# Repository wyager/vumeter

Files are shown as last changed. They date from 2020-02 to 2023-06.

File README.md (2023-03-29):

# Nixie Tube Audio Meter

Picture of VU meter

A full writeup is available [here](http://yager.io/vumeter/vu.html).

## Directory Structure
* schematics
    * tube-board - the board that powers and controls the nixie tubes
    * tube-offset-1,2 - PCBs that hold the tubes in place
    * audio-board - a teensy-based board that takes in S/PDIF audio over TOSLINK, does DSP, and outputs control data to the tube boards
    * custom - custom kicad parts for this project
    * case - freecad designs and macros for the case, plus some resultant SVGs I used to laser-cut the acrylic
    * bom - a list of some non-commodity part numbers
* code
    * audio-board - the code for the board that reads in S/PDIF audio over TOSLINK, does DSP, and controls the tube boards
    * linux-control - some code for controlling the tube boards from Linux/mac. Mostly used for testing.
    * test - used for testing the DSP code on desktop
    * tube-board - code for the board that powers/controls the bargraph tubes
    * vumeter-lib - hardware-independent code

## Building the code

Go into `code/audio_board` and `code/tube_board` and run `cargo build --release`. (Without `--release`, the binaries may be too large.)

## Uploading the code

First, build the code.

### Tube board

Go into `code/tube_board`.

Plug your AVR-ICE or similar JTAG programmer into the tube board via the programming header and run `./program.sh`.

### Audio Board

Go into `code/audio_board`.

Plug in your teensy over USB, put it in programming mode, and run `./program.sh`

## Building the PCBs

Get KiCad and open the schematics. How to export the schematics depends on your choice of PCB manufacturer. They should have instructions available online.

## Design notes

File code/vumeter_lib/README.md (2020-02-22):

This library contains the hardware-independent bits of the vumeter project, including:

* Packet protocol definitions, parsers/formatters, etc. etc.
* DSP code
* The core logic of the audio and tube boards, with the hardware details abstracted away

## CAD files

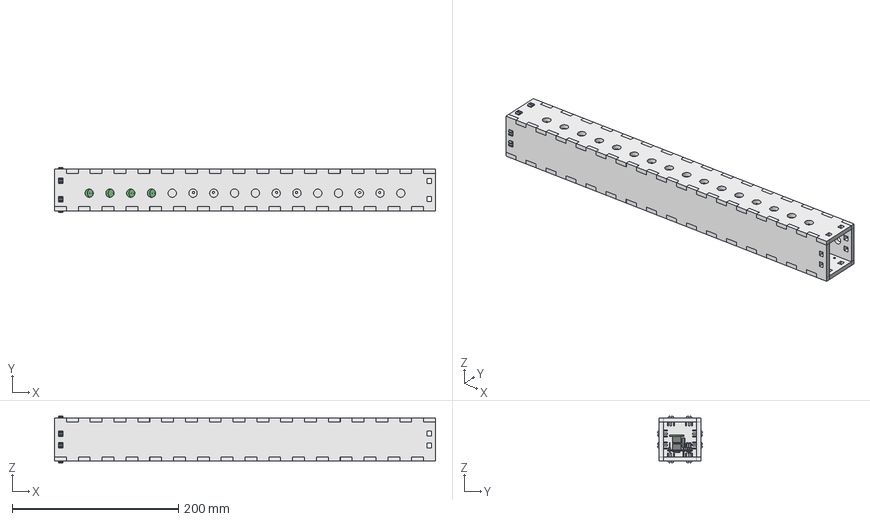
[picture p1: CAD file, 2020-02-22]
schematics/case/bottom.FCStd
458.4 x 54.2 x 56.2 mm
offset-b-001
base_extr
back_extr
front_extr
top_extr
side_extr

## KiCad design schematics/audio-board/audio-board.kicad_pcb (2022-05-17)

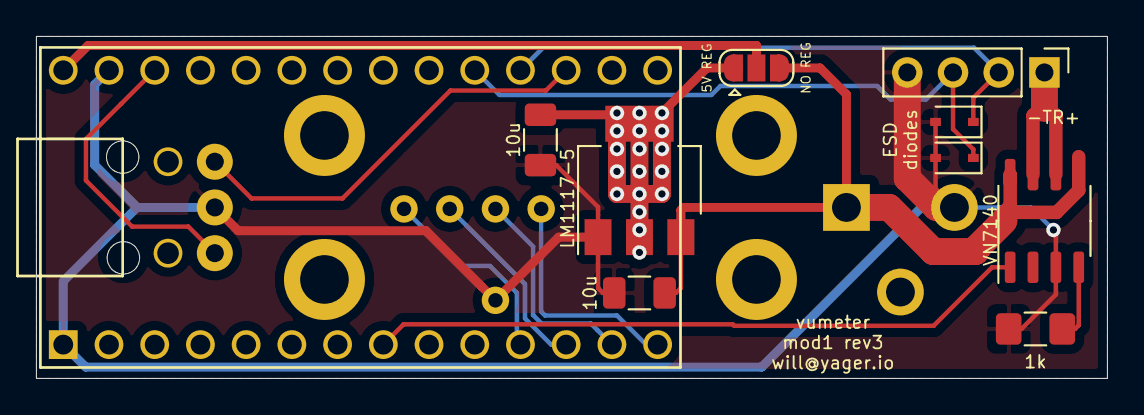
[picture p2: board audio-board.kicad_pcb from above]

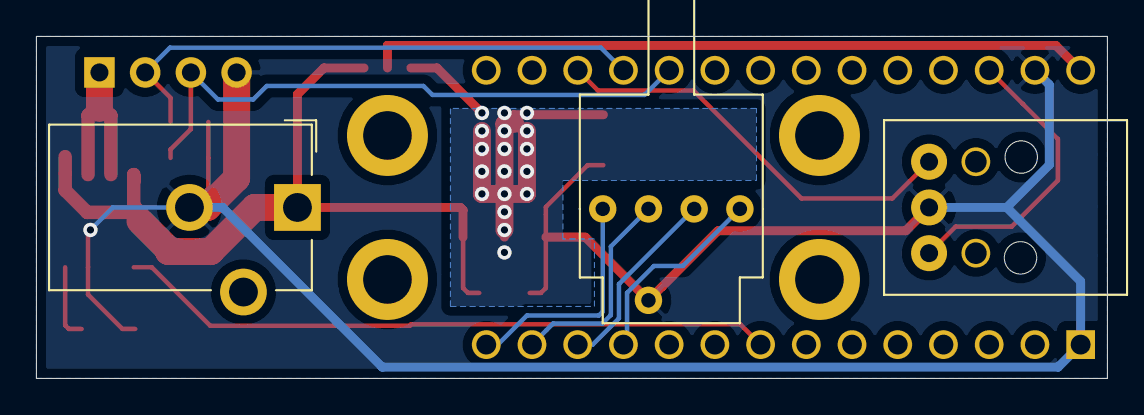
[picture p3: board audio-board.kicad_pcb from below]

Board: 2 copper layers, 59.5 x 19.0 mm, 17 parts (3 on the bottom side), 15 nets.

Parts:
C_pwr1, C_pwr2: 10u; C_1206_3216Metric
D1, D2: BZX384-xxx; D_SOD-323
H1, H2, H3, H4: MountingHole_Pad; MountingHole_2.7mm_M2.5_ISO14580_Pad
J3: Conn_01x04; PinHeader_1x04_P2.54mm_Vertical
J4: Conn_Coaxial_Power; BarrelJack_CUI_PJ-102AH_Horizontal
R1: 1k; R_1206_3216Metric_Pad1.42x1.75mm_HandSolder
SW1: 5V_BYPASS; SolderJumper-3_P1.3mm_Open_RoundedPad1.0x1.5mm
U1: Teensy4.0; Teensy40
U2: spdif_recv; Cliff_ORJ-8
U3: LM1117-5; SOT-223-3_TabPin2
U5: S-2151
U6: VN7140; SO-8_3.9x4.9mm_P1.27mm

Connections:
3V3: U1.31, U2.3
5V: C_pwr2.1, SW1.1, U3.2
GND: C_pwr1.1, C_pwr2.2, D1.2, D2.2, J3.4, J4.2, R1.1, U1.1, U1.32, U2.2, U3.1, U5.5, U6.3
unnamed: R1.2, U6.4
unnamed: U1.11, U5.4
unnamed: U1.12, U5.3
unnamed: U1.13, U5.2
unnamed: U1.14, U5.1
unnamed: U1.22, U2.1
TEENSY_5V_SUPPLY: SW1.2, U1.33
V_mid: C_pwr1.2, J4.1, SW1.3, U3.3, U6.5, U6.8
V_mid_out: J3.1, U6.6, U6.7
output_power_en: U1.8, U6.1
rx2: D2.1, J3.2, U1.23
tx2: D1.1, J3.3, U1.24

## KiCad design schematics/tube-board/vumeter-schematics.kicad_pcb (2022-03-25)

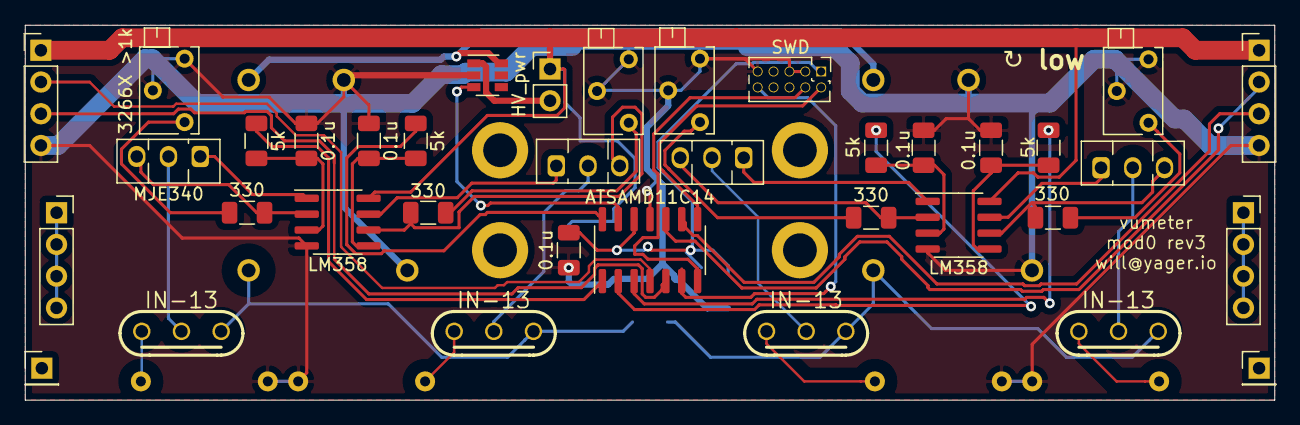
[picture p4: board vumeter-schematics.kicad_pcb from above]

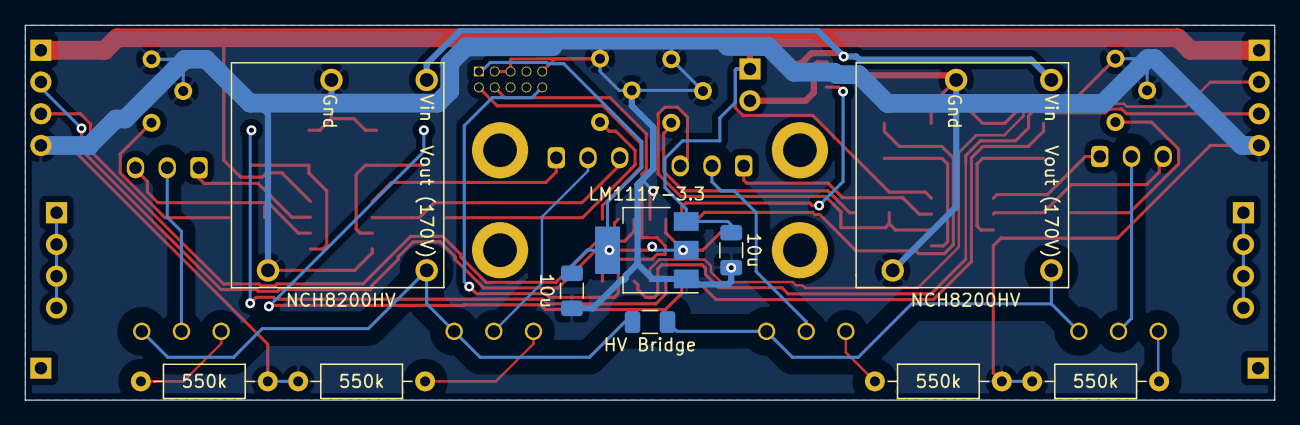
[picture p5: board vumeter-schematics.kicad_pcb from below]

Board: 2 copper layers, 100.0 x 30.0 mm, 51 parts (10 on the bottom side), 45 nets.

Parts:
C_decouple1: 0.1u; C_1206_3216Metric
C_pwm1, C_pwm2, C_pwm3, C_pwm4: 0.1u; C_1206_3216Metric
C_pwr1, C_pwr2: 10u; C_1206_3216Metric
H1, H2, H3, H4: MountingHole_Pad; MountingHole_2.7mm_M2.5_ISO14580_Pad
J1: SWD; PinHeader_2x05_P1.27mm_Vertical-smallholes
J2, J3: Conn_01x04; PinHeader_1x04_P2.54mm_Vertical
J4: Standoff_1; PinSocket_1x04_P2.54mm_Vertical
J5: Standoff_2; PinSocket_1x04_P2.54mm_Vertical
J6, J7: Conn_01x01_Male; PinHeader_1x01_P2.54mm_Vertical
JP1: HV Bridge; R_1206_3216Metric
JP2: HV_pwr; PinHeader_1x02_P2.54mm_Vertical
N1, N2, N3, N4: IN-13; fixed-IN-13-footprint-wide-sockets
Q1, Q2, Q3, Q4: MJE340; TO-126-3_Vertical-HV
R_Cathode1, R_Cathode2, R_Cathode3, R_Cathode4: 550k; R_Axial_DIN0207_L6.3mm_D2.5mm_P10.16mm_Horizontal
R_Sense1, R_Sense2, R_Sense3, R_Sense4: 330; R_1206_3216Metric
R_adj1, R_adj2, R_adj3, R_adj4: 3266X >1k; Potentiometer_Bourns_3266X_Horizontal
R_pwm1, R_pwm2, R_pwm3, R_pwm4: 5k; R_1206_3216Metric
U1, U4: LM358; SOIC-8_3.9x4.9mm_P1.27mm
U2: ATSAMD11C14; SOIC-14_3.9x8.7mm_P1.27mm
U3: LM1117-3.3; SOT-223-3_TabPin2
U5, U6: NCH8200HV
U7: TPS2281DBVR; SOT-23-6

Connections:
3V3: C_decouple1.1, C_pwr2.1, J1.1, U2.12, U3.2
GND: C_decouple1.2, C_pwm1.2, C_pwm2.2, C_pwm3.2, C_pwm4.2, C_pwr1.1, C_pwr2.2, J1.3, J1.5, J1.9, J2.4, J3.4, R_Cathode1.2, R_Cathode2.2, R_Cathode3.2, R_Cathode4.2, R_adj1.2, R_adj1.3, R_adj2.2, R_adj2.3, R_adj3.2, R_adj3.3, R_adj4.2, R_adj4.3, U1.4, U2.11, U3.1, U4.4, U5.2, U5.3, U6.2, U6.3, U7.2
HV1: JP1.2, N1.A, N2.A, U5.4
HV2: JP1.1, N3.A, N4.A, U6.4
M1: N1.K2, Q1.2
M2: N2.K2, Q2.2
M3: N3.K2, Q3.2
M4: N4.K2, Q4.2
M5: N1.K, R_Cathode1.1
M6: N2.K, R_Cathode2.1
M7: N3.K, R_Cathode3.1
M8: N4.K, R_Cathode4.1
unnamed: C_pwm1.1, R_pwm1.2, U1.3
unnamed: C_pwm2.1, R_pwm2.2, U1.5
unnamed: C_pwm3.1, R_pwm3.2, U4.3
unnamed: C_pwm4.1, R_pwm4.2, U4.5
unnamed: J4.1, J4.2, J4.3, J4.4
unnamed: J5.1, J5.2, J5.3, J5.4
unnamed: JP2.2, U7.1
unnamed: Q1.1, U1.1
unnamed: Q1.3, R_Sense1.1, U1.2
unnamed: Q2.1, U1.7
unnamed: Q2.3, R_Sense2.1, U1.6
unnamed: Q3.1, U4.1
unnamed: Q3.3, R_Sense3.1, U4.2
unnamed: Q4.1, U4.7
unnamed: Q4.3, R_Sense4.1, U4.6
unnamed: R_Sense1.2, R_adj1.1
unnamed: R_Sense2.2, R_adj2.1
unnamed: R_Sense3.2, R_adj3.1
unnamed: R_Sense4.2, R_adj4.1
unnamed: U5.1, U6.1, U7.6
PWM1: R_pwm1.1, U2.1
PWM2: R_pwm2.1, U2.14
PWM3: R_pwm3.1, U2.2
PWM4: R_pwm4.1, U2.3
V_mid: C_pwr1.2, J2.1, J3.1, JP2.1, U1.8, U3.3, U4.8
hv_en: U2.13, U7.3
rst: J1.10, U2.6
rx1: J2.2, U2.10
rx2: J3.3, U2.5
swclk: J1.4, U2.7
swdio: J1.2, U2.8
tx1: J2.3, U2.9
tx2: J3.2, U2.4

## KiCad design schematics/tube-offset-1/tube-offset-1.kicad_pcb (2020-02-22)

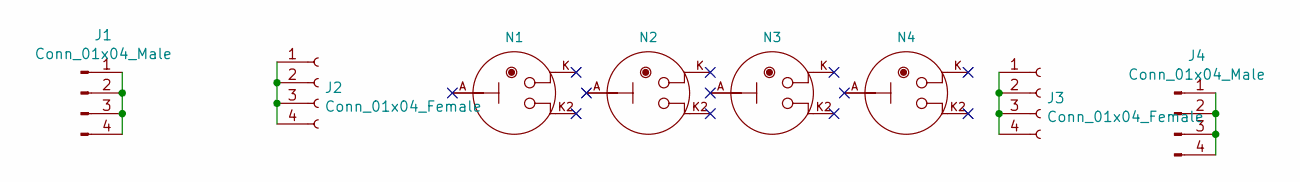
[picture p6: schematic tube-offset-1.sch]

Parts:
J1, J4: Conn_01x04_Male; PinSocket_1x04_P2.54mm_Vertical
J2, J3: Conn_01x04_Female; PinSocket_1x04_P2.54mm_Vertical
N1, N2, N3, N4: IN-13; fixed-IN-13-footprint

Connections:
unnamed: J1.1, J1.2, J1.3, J1.4
unnamed: J2.1, J2.2, J2.3, J2.4
unnamed: J3.1, J3.2, J3.3, J3.4
unnamed: J4.1, J4.2, J4.3, J4.4

Board: 2 copper layers, 8 parts (0 on the bottom side), 4 nets, no tracks yet.

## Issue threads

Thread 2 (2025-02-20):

Calibrate IN-13 !! PLZ !!!

0Bender, 2025-02-20:
I assembled a similar device from @holingher and it worked from the first launch :) https://github.com/holingher/vumeter_IN13
I have only one question. How to adjust the lamp level? How to set the maximum on the dumps? Maybe there is some kind of calibration? Thank you.

The author does not answer, but the devices are very similar.
I will be glad to any advice.

wyager, 2025-02-20:
Assuming the designs are similar, the blue trimpots are used to adjust the maximum tube level. On my design, there's a mode that puts all tubes to 100% so you can see where the max level sits as you adjust. Hope that helps!

0Bender, 2025-02-21:
Yes. I know about resistors :)
However, I tried to supply signals of different levels, but I still didn't understand which one is correct. 0dB or not. The maximum level mode only works when turned on.
However, because the code is different, I think I'll have to look for this mode from the developer.
Thanks!

Closed 2025-02-20.

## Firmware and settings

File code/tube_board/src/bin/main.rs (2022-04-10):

#![no_std]
#![no_main]

extern crate cortex_m_rt;
extern crate panic_halt;
extern crate vumeter_lib as vu;
extern crate atsamd11c;

#[macro_use(block)]
extern crate nb;



use atsamd_hal::clock::GenericClockController;
use samd11_bare::pac::{Peripherals,CorePeripherals};
use atsamd_hal::prelude::*;
use samd11_bare::pac::gclk::clkctrl::GEN_A;
use samd11_bare::pac::gclk::genctrl::SRC_A;
use atsamd_hal::sercom::{Sercom0, Sercom1};//{PadPin, Sercom0Pad0, Sercom0Pad1, Sercom1Pad2, Sercom1Pad3, UART0, UART1};
use embedded_hal::serial::{Read,Write};
use atsamd_hal::timer::TimerCounter;
// TODO: Figure out if one of the 2022 crates has wfi
//use cortex_m::asm::wfi;
use atsamd_hal::pwm::{Channel,Pwm0};
use atsamd_hal::time::{Hertz,KiloHertz};
use atsamd_hal::delay::Delay;
use atsamd_hal::gpio::{AlternateE, AlternateF, AlternateC};
use atsamd_hal::gpio::pin::{PA02, PA04, PA05, PA08, PA09, PA14, PA15, PA24, PA25};
use atsamd_hal::gpio::Pin;
use atsamd_hal::sercom::uart as uart;
use atsamd_hal::sercom::uart::BaudMode;
use atsamd_hal::sercom::uart::Oversampling;
use atsamd_hal::gpio::PushPullOutput;

use vu::tube_hw as hw;

use vu::shared::{RingBuf};
use hw::PWMPin::{A,B,C,D};

use samd11_bare::entry;

struct PowerPin(Pin<PA02, PushPullOutput>);

impl hw::DigitalOutput for PowerPin {
    fn set(&mut self, on : bool) {
        if on {self.0.set_high().unwrap()} else {self.0.set_low().unwrap()}
    }
}

struct PWMPins {
    pwm:Pwm0, _p1:Pin<PA04,AlternateF>, _p2:Pin<PA05,AlternateF>, _p3:Pin<PA08,AlternateE>, _p4:Pin<PA09,AlternateE>
}

impl hw::PWMx4 for PWMPins {
    fn get_max_duty(&self) -> u32 { self.pwm.get_max_duty() }
    fn set_duty(&mut self, pin : hw::PWMPin, duty : u32) {
        match pin {
            A => {self.pwm.set_duty(Channel::_1,duty)},
            B => {self.pwm.set_duty(Channel::_0,duty)},
            C => {self.pwm.set_duty(Channel::_2,duty)},
            D => {self.pwm.set_duty(Channel::_3,duty)}
        }
    }
}

#[entry]
fn main() -> ! {
    let mut peripherals = Peripherals::take().unwrap();
    let core = CorePeripherals::take().unwrap();

    // Initialize clocks
    let mut clocks = GenericClockController::with_internal_32kosc(
        peripherals.GCLK,
        &mut peripherals.PM,
        &mut peripherals.SYSCTRL,
        &mut peripherals.NVMCTRL,
    );
    clocks.configure_gclk_divider_and_source(GEN_A::GCLK2, 1, SRC_A::DFLL48M, false);
    let mut delay = Delay::new(core.SYST, &mut clocks);

    // Initialize 20Hz timer
    let gclk0 = clocks.gclk0();
    let timer_clock = clocks.tc1_tc2(&gclk0).unwrap();
    let mut timer = TimerCounter::tc1_(&timer_clock, peripherals.TC1, &mut peripherals.PM);
    timer.start(Hertz(20));

    // Initialize TCC0 PWM subsystem
    let tcc0clk = clocks.tcc0(&gclk0).unwrap();
    let pwm = Pwm0::new(&tcc0clk, KiloHertz(10), peripherals.TCC0, &mut peripherals.PM);

    let pins = samd11_bare::Pins::new(peripherals.PORT);
    // Enable PWM pins
    let p1 : Pin<PA04, AlternateF> = pins.d14.into_mode(); // parts.pa4.into_function_f(&mut parts.port);
    let p2 : Pin<PA05, AlternateF> = pins.d1.into_mode(); //parts.pa5.into_function_f(&mut parts.port);
    let p3 : Pin<PA08, AlternateE> = pins.d2.into_mode(); //parts.pa8.into_function_e(&mut parts.port);
    let p4 : Pin<PA09, AlternateE> = pins.d3.into_mode(); //parts.pa9.into_function_e(&mut parts.port);

    let pwm = PWMPins{pwm,_p1:p1,_p2:p2,_p3:p3,_p4:p4};

    // Initialize both left and right UARTs
    let gclk2 = clocks.get_gclk(GEN_A::GCLK2).expect("Could not get clock 2");
    let mut u1 = { 
        //let tx1: Sercom1Pad2<_> = parts.pa24.into_pull_down_input(&mut parts.port).into_pad(&mut parts.port);
        let tx1 : Pin<PA24, AlternateC> = pins.d9.into();
        //let rx1: Sercom1Pad3<_> = parts.pa25.into_pull_down_input(&mut parts.port).into_pad(&mut parts.port);
        let rx1 : Pin<PA25, AlternateC> = pins.d10.into();
        let uart_clk = clocks.sercom1_core(&gclk2).expect("Could not configure sercom1 clock");
        let pads = uart::Pads::<Sercom1>::default().rx(rx1).tx(tx1);
        //UART1::new(&uart_clk,Hertz(460800),peripherals.SERCOM1,&mut peripherals.PM,(rx1, tx1))
        let config = uart::Config::new(&peripherals.PM, peripherals.SERCOM1, pads, uart_clk.freq());
        let config = config.baud(Hertz(460800), BaudMode::Fractional(Oversampling::Bits16));
        config.enable()
    };

    let mut u2 = { 
        // let tx2: Sercom0Pad0<_> = parts.pa14.into_pull_down_input(&mut parts.port).into_pad(&mut parts.port);
        // let rx2: Sercom0Pad1<_> = parts.pa15.into_pull_down_input(&mut parts.port).into_pad(&mut parts.port);
        // let uart_clk = clocks.sercom0_core(&gclk2).expect("Could not configure sercom0 clock");
        // UART0::new(&uart_clk,460800u32.hz(),peripherals.SERCOM0,&mut peripherals.PM,(rx2, tx2))
        let tx2 : Pin<PA14, AlternateC> = pins.d4.into();
        let rx2 : Pin<PA15, AlternateC> = pins.d5.into();
        let uart_clk = clocks.sercom0_core(&gclk2).expect("Could not configure sercom1 clock");
        let pads = uart::Pads::<Sercom0>::default().rx(rx2).tx(tx2);
        let config = uart::Config::new(&peripherals.PM, peripherals.SERCOM0, pads, uart_clk.freq());
        let config = config.baud(Hertz(460800), BaudMode::Fractional(Oversampling::Bits16));
        config.enable()
    };



    // Initialize HV controller and activate HV boost circuit
    let hv_pwr_en = PowerPin(pins.d13.into_push_pull_output());
    let mut state = hw::State::new(hv_pwr_en,pwm);


    use hw::Event::*;

    

    // Forwarding buffers. If there's a message intended for another board,
    // we dump its contents in here and send it as the opportunity arises.
    let mut u1_buf = [0;64];
    let mut u1_buf = RingBuf::new(&mut u1_buf);
    let mut u2_buf = [0;64];
    let mut u2_buf = RingBuf::new(&mut u2_buf);

    
    // Give secondary cathodes time to fire
    for _ in 0..=hw::ENERGIZE_TICKS {
        block!(timer.wait()).unwrap();
        state.update(TimerFired, &mut u1_buf, &mut u2_buf);
    };

    // Display startup animation
    state.display_startup_pattern(&mut || delay.delay_ms(1u8));
    
    
    loop {
        // If there's anything in the forward buffers, dump as much as we can to the UART.
        while let Some(()) = u1_buf.with_front(|byte| u1.write(byte).ok()) {}
        while let Some(()) = u2_buf.with_front(|byte| u2.write(byte).ok()) {}

        // Read a byte from either serial port
        let rx1 = u1.read().ok().map(Rx1);
        let rx2 = u2.read().ok().map(Rx2);
        // See if the timer fired
        let tmr = timer.wait().ok().map(|()| TimerFired);
        
        if rx1.is_none() && rx2.is_none() && tmr.is_none() {
            // wfi() // Doesn't seme to work properly on this board.
        } else {
            for evt in rx1.into_iter().chain(rx2.into_iter()).chain(tmr.into_iter()) {
                state.update(evt, &mut u1_buf, &mut u2_buf);
            }
        }
    }

}

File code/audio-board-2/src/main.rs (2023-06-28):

//! The starter code slowly blinks the LED, sets up
//! USB logging, and creates a UART driver using pins
//! 14 and 15. The UART baud rate is [`UART_BAUD`].
//!
//! Despite targeting the Teensy 4.0, this starter code
//! also works on the Teensy 4.1.

#![no_std]
#![no_main]

use bsp::board;
use teensy4_bsp as bsp;
use teensy4_panic as _;

use bsp::hal::timer::Blocking;

use core::fmt::Write as _;

/// CHANGE ME to vary the baud rate.
const UART_BAUD: u32 = 115200;
/// Milliseconds to delay before toggling the LED
/// and writing text outputs.
const DELAY_MS: u32 = 500;

#[bsp::rt::entry]
fn main() -> ! {
    // These are peripheral instances. Let the board configure these for us.
    // This function can only be called once!
    let instances = board::instances();

    // Driver resources that are configured by the board. For more information,
    // see the `board` documentation.
    let board::Resources {
        // `pins` has objects that represent the physical pins. The object
        // for pin 13 is `p13`.
        pins,
        // This is a hardware timer. We'll use it for blocking delays.
        mut gpt1,
        // These are low-level USB resources. We'll pass these to a function
        // that sets up USB logging.
        usb,
        // This is the GPIO2 port. We need this to configure the LED as a
        // GPIO output.
        mut gpio2,
        // This resource is for the UART we're creating.
        lpuart2,
        ..
    } = board::t40(instances);

    // When this returns, you can use the `log` crate to write text
    // over USB. Use either `screen` (macOS, Linux) or PuTTY (Windows)
    // to visualize the messages from this example.
    bsp::LoggingFrontend::default_log().register_usb(usb);

    // This configures the LED as a GPIO output.
    let led = board::led(&mut gpio2, pins.p13);

    // Configures the GPT1 timer to run at GPT1_FREQUENCY. See the
    // constants below for more information.
    gpt1.disable();
    gpt1.set_divider(GPT1_DIVIDER);
    gpt1.set_clock_source(GPT1_CLOCK_SOURCE);

    // Convenience for blocking delays.
    let mut delay = Blocking::<_, GPT1_FREQUENCY>::from_gpt(gpt1);

    // Create the UART driver using pins 14 and 15.
    // Cast it to a embedded_hal trait object so we can
    // use it with the write! macro.
    let mut lpuart2: board::Lpuart2 = board::lpuart(lpuart2, pins.p14, pins.p15, UART_BAUD);
    let lpuart2: &mut dyn embedded_hal::serial::Write<u8, Error = _> = &mut lpuart2;

    let mut counter: u32 = 0;
    loop {
        led.toggle();
        log::info!("Hello from the USB logger! The count is {counter}");
        write!(
            lpuart2,
            "Hello from the UART driver! The count is {counter}\r\n"
        )
        .ok();

        delay.block_ms(DELAY_MS);
        counter = counter.wrapping_add(1);
    }
}

// We're responsible for configuring our timers.
// This example uses PERCLK_CLK as the GPT1 clock source,
// and it configures a 1 KHz GPT1 frequency by computing a
// GPT1 divider.
use bsp::hal::gpt::ClockSource;

/// The intended GPT1 frequency (Hz).
const GPT1_FREQUENCY: u32 = 1_000;
/// Given this clock source...
const GPT1_CLOCK_SOURCE: ClockSource = ClockSource::HighFrequencyReferenceClock;
/// ... the root clock is PERCLK_CLK. To configure a GPT1 frequency,
/// we need a divider of...
const GPT1_DIVIDER: u32 = board::PERCLK_FREQUENCY / GPT1_FREQUENCY;
